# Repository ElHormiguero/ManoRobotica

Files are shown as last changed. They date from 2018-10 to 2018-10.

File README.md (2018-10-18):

# ManoRobotica

Se trata de un brazo robótico impreso en 3d y a escala real, su diseño es de un proyecto de código libre de [grossrc](https://www.thingiverse.com/thing:2269115) al que se le ha añadido dos articulaciones adicionales que añaden grados de libertad. 5 servomotores mueven los dedos gracias a un hilo que simula el tendón humano, el movimiento del dedo gordo se reproduce con dos servos, mientras que el dedo anular y meñique comparten uno solo. Además, un sistema de articulación le permite rotar en los 3 ejes posibles.
El control se realiza mediante un guante que incorpora sensores de flexión en cada dedo y un acelerómetro para obtener la rotación de la mano, los datos se envían por radiofrecuencia a una velocidad de 20 muestras por segundo.



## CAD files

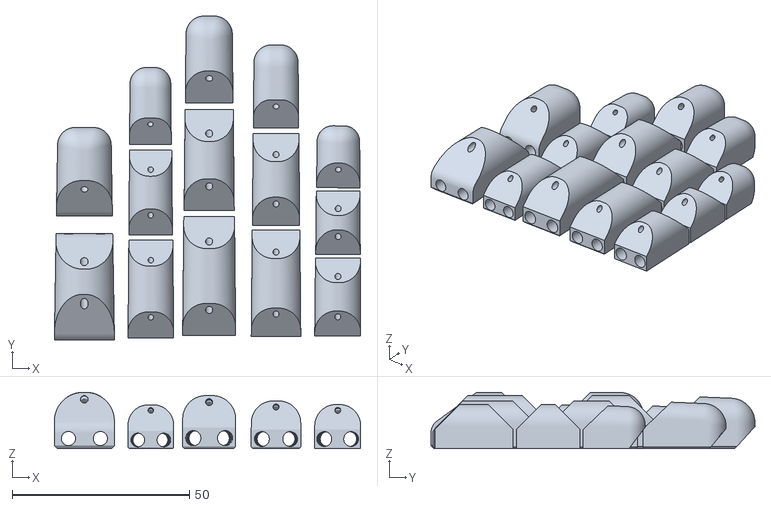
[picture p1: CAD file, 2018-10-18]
Piezas 3D/1Fingerdesign_ALL.stl
86.5 x 91.5 x 15.8

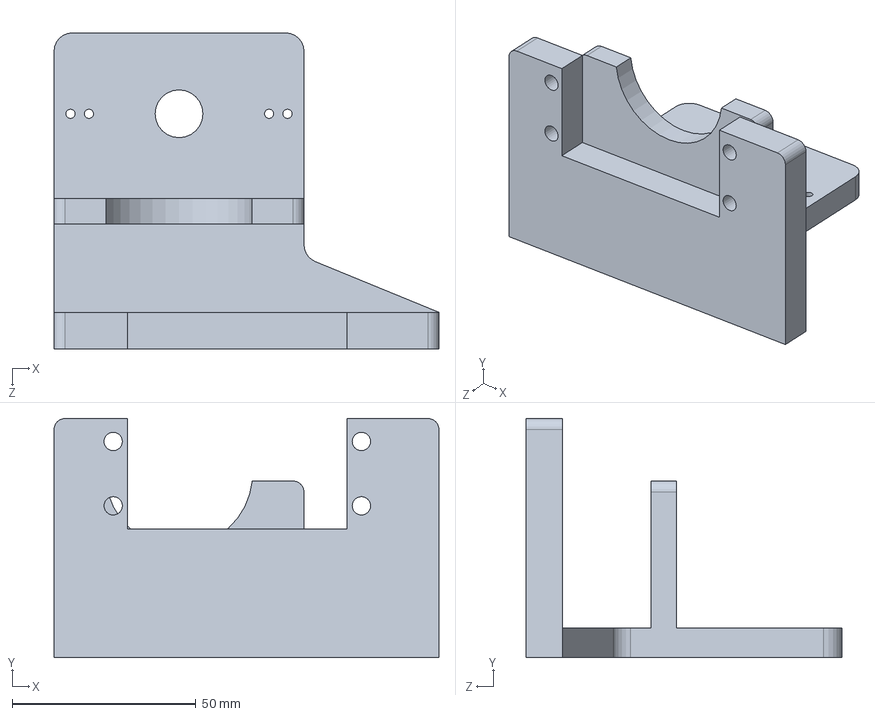
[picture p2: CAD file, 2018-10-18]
Piezas 3D/Piezas añadidas/Articulacion.SLDPRT
104.7 x 65.0 x 86.0 mm

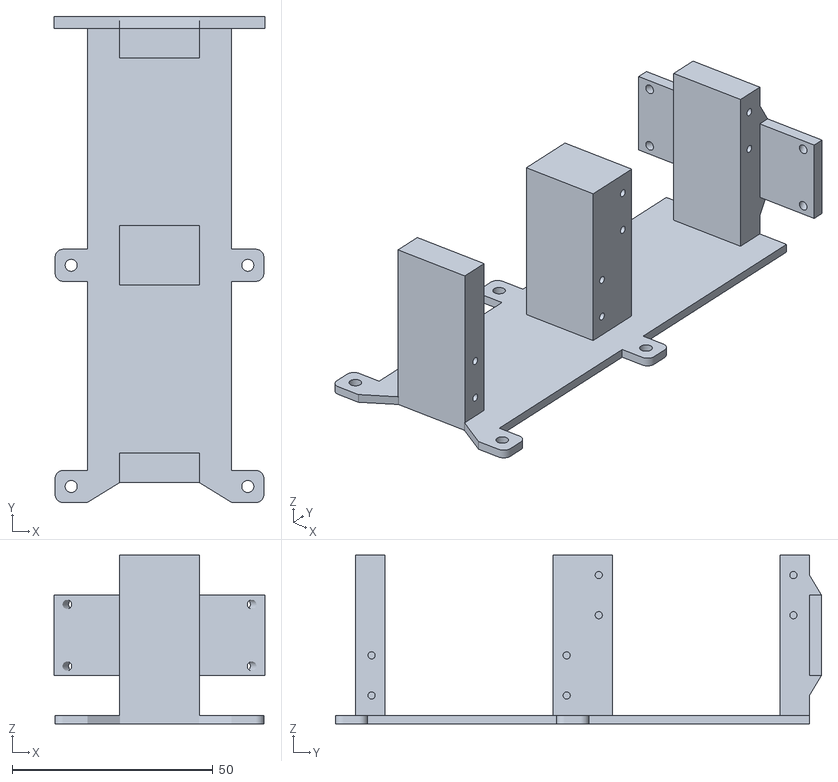
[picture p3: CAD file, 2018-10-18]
Piezas 3D/3Servo_Hold.stl
52.6 x 121.1 x 42.1

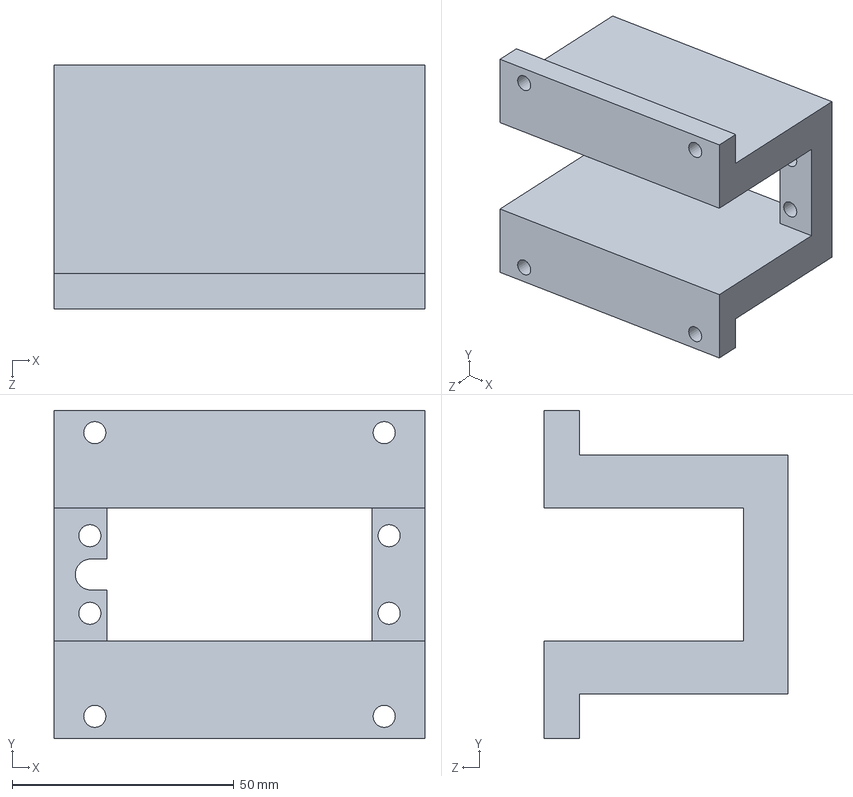
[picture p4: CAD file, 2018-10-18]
Piezas 3D/Piezas añadidas/Base.SLDPRT
83.7 x 74.0 x 55.0 mm

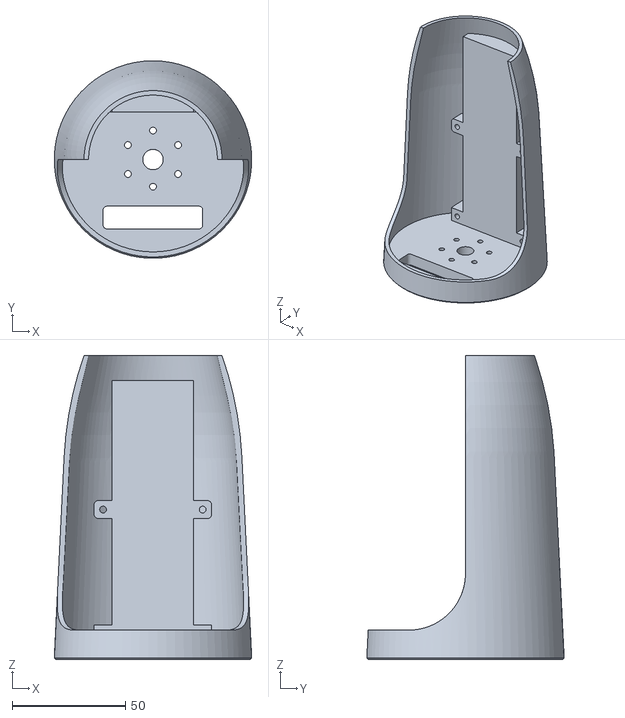
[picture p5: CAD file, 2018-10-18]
Piezas 3D/2Forarm_9-2.stl
87.3 x 87.3 x 134.4

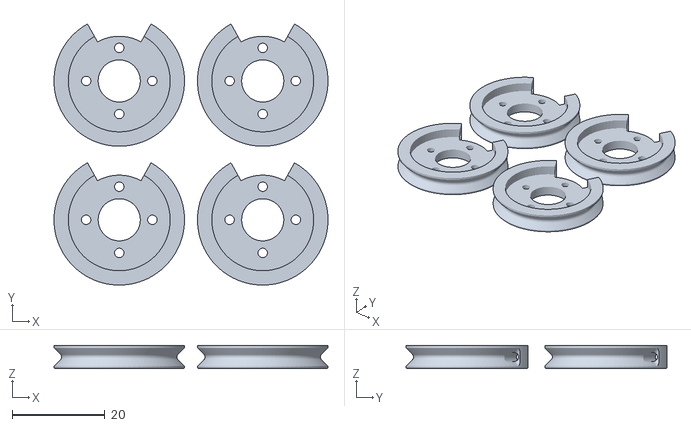
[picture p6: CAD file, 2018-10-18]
Piezas 3D/4ServoHorn.stl
59.2 x 56.4 x 5.00

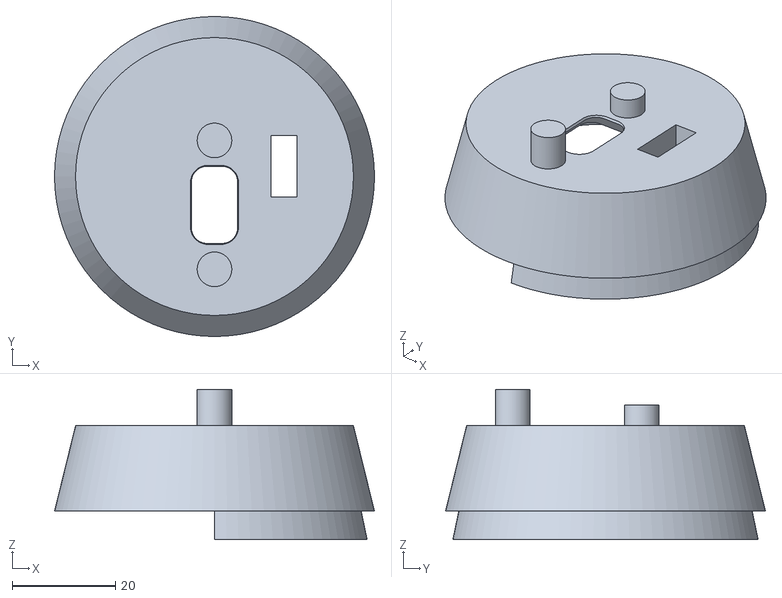
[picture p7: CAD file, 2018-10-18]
Piezas 3D/2Forarm_9-3.stl
62.1 x 62.1 x 29.1

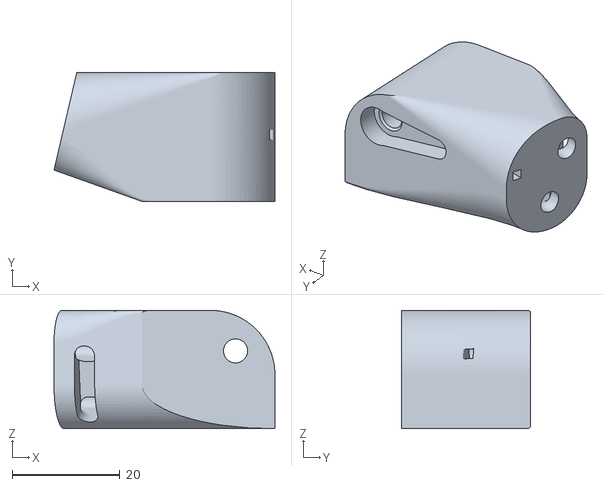
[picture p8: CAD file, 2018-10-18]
Piezas 3D/4Hand5Thumb3.stl
41.1 x 24.0 x 22.0

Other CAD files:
Piezas 3D/Piezas añadidas/Articulacion.STL
Piezas 3D/Piezas añadidas/Base.STL

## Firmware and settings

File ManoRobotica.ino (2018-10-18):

/*
  Brazo robótico con tensores movidos por servomotores según la flexión de los sensores y control de la orientación por un acelerómetro
  Autor: Javier Vargas. El Hormiguero.
  Diseño 3D de grossrc bajo licencia Creative Commons - Attribution - Non-Commercial (https://www.thingiverse.com/thing:2269115)
  https://creativecommons.org/licenses/by-nc/3.0/
*/

/*Conexion de servos
  0 - Articulacion dedo gordo PCA9685 --> 0 (EMAX ES08A) --> V: Step Down D24V50F5
  1 - Dedo gordo PCA9685              --> 1 (MG996R) --> V: Step Down D24V50F5
  2 - Dedo índice PCA9685             --> 2 (MG996R) --> V: Step Down D24V50F5
  3 - Dedo medio PCA9685              --> 3 (MG996R) --> V: Step Down D24V50F5
  4 - Dedo anular + meñique PCA9685   --> 4 (MG996R) --> V: Step Down D24V50F5
  5 - Angulo roll PCA9685             --> 5 (MG996R) --> V: Step Down D24V50F5
  6 - Angulo pitch PWM Arduino        --> 5 (POWER HD 1235MG) --> V: Vbat 7.4V - 2 diodos
  7 - Angulo yaw PWM Arduino          --> 7 (POWER HD 1235MG) --> V: Vbat 7.4V - 2 diodos
*/

//PINES
#define CE_PIN 3
#define CSN_PIN 10
#define PinServoPWM_6 5 //Servo pwm Pitch
#define PinServoPWM_7 7 //Servo pwm Yaw
//Servos conectados de la salida 0 a la 8 del driver
//CONFIGURACION
#define Nservos 9
#define Ndatos 8
#define TimeCero 1000 //(ms) Tiempo sin recibir datos para volver a la posicion inicial

//Servo MG996R (Driver)
#define SERVOMIN  125 // Anchura minima de señal PWM 
#define SERVOMAX  580 // Anchura maxima de señal PWM 
#define ANGULOMAX 220 //Angulo máximo 

//Servo EMAX ES08A (Driver)
#define mSERVOMIN  220 // Anchura minima de señal PWM 
#define mSERVOMAX  580 // Anchura maxima de señal PWM 
#define mANGULOMAX 165 //Angulo máximo

//Servo POWER HD 1235MG (PWM)
#define gSERVOMIN  544 // Anchura minima de señal PWM 
#define gSERVOMAX  2390 // Anchura maxima de señal PWM   
//Angulo de 180º

//Sensor de los dedos (0-gordo, 1-índice, 3-medio, 4-anular, 5-meñique)
const int SensFlex[] = {610, 560, 540, 550, 570};
const int SensNoFlex[] = {780, 780, 780, 745, 785};
//Angulo de los dedos (0-art.gordo, 1-gordo, 2-índice, 3-medio, 4-anular+meñique)
const int AngFlex[] = {50, 170, 115, 60, 50};
const int AngNoFlex[] = {110, 60, 220, 180, 170};
//Angulo de los ejes (0-yaw, 1-pitch, 2-roll)
const int AngMax[] = {180, 120, 180};
const int AngMin[] = {0, 70, 0};
const int AngCero[] = {75, 90, 90};
//Offset
const int Offset[] = {0, 0, 0};

//DRIVER SERVOS PCA
#include <Wire.h>
#include <Adafruit_PWMServoDriver.h>
Adafruit_PWMServoDriver pwm = Adafruit_PWMServoDriver(); //Direccion 0x40
//SERVO POR PWM (ALIMENTADO POR BATERIA)
#include <Servo.h>
Servo servo6, servo7;

//NRF24L01
byte direccion[5] = {'h', 'o', 'r', 'm', 'i'}; //Variable con la dirección del canal por donde se va a transmitir
#include <SPI.h>
#include <nRF24L01.h>
#include <RF24.h>
RF24 radio(CE_PIN, CSN_PIN);
float Datos[Ndatos] = {0, 0, 0, 0, 0, 0, 0, 0};

unsigned long m = 0;
boolean e = 0;

void setup() {
  Serial.begin(115200);

  //Inicio driver servos
  pwm.begin();
  pwm.setPWMFreq(60);  //Frecuencia de 60Hz en servos analógicos

  //Inicio del NRF24L01
  radio.begin();
  radio.openReadingPipe(1, direccion);
  radio.startListening();   //empezamos a escuchar por el canal
  delay(500);


  //Inicio servos pwm
  servo6.attach(PinServoPWM_6, gSERVOMIN, gSERVOMAX);
  servo7.attach(PinServoPWM_7, gSERVOMIN, gSERVOMAX);

}

//////////////////////////////////
///////////////LOOP///////////////
//////////////////////////////////

void loop() {

  //DATOS RECIBIDOS POR RF
  if (radio.available()) {
    m = millis();
    //Datos recibidos por RF
    radio.read(Datos, sizeof(Datos));
    //Rotamos el brazo segun Yaw, Pitch y Roll
    RotarBrazo(Datos[0], Datos[1], Datos[2]);
    //Movemos los dedos sengun los sensores de flexion
    MoverDedos(Datos[3], Datos[4], Datos[5], Datos[6], Datos[7]);
  }

  //Vuelta a la posicion inicial si no recibe datos en TimeCero ms
  if (millis() > m + TimeCero) ServoCero();


}

//////////////////////////////////
//////////////////////////////////
//////////////////////////////////

void RotarBrazo(float yaw, float pitch, float roll) {
  //Yaw
  int AngYaw = constrain(AngCero[0] - yaw - Offset[0], AngMin[0], AngMax[0]);
  MoverServo(7, AngYaw);
  //Pitch
  int AngPitch = constrain(AngCero[1] - pitch - Offset[1], AngMin[1], AngMax[1]);
  MoverServo(6, AngPitch);
  //Roll
  int AngRoll = constrain(AngCero[2] + roll + Offset[2], AngMin[2], AngMax[2]);
  MoverServo(5, AngRoll);
}

void MoverDedos(int d1, int d2, int d3, int d4, int d5) {
  //Articulacion dedo gordo + dedo
  d1 = constrain(d1, SensFlex[0], SensNoFlex[0]);
  MoverServo(0, map(d1, SensFlex[0], SensNoFlex[0], AngFlex[0], AngNoFlex[0]));
  MoverServo(1, map(d1, SensFlex[0], SensNoFlex[0], AngFlex[1], AngNoFlex[1]));
  //Dedo índice
  d2 = constrain(d2, SensFlex[1], SensNoFlex[1]);
  MoverServo(2, map(d2, SensFlex[1], SensNoFlex[1], AngFlex[2], AngNoFlex[2]));
  //Dedo medio
  d3 = constrain(d3, SensFlex[2], SensNoFlex[2]);
  MoverServo(3, map(d3, SensFlex[2], SensNoFlex[2], AngFlex[3], AngNoFlex[3]));
  //Dedo anular + meñique
  d4 = constrain(d4, SensFlex[3], SensNoFlex[3]);
  d5 = constrain(d5, SensFlex[4], SensNoFlex[4]);
  int dMed = (d4 + d5) / 2;
  int SensFlexMed = (SensFlex[3] + SensFlex[4]) / 2;
  int SensNoFlexMed = (SensNoFlex[3] + SensNoFlex[4]) / 2;
  MoverServo(4, map(dMed, SensFlexMed, SensNoFlexMed, AngFlex[4], AngNoFlex[4]));
}

void MoverServo(int S, int A) {
  //EMAX ES08A
  if (S == 0) {
    pwm.setPWM(S, 0, map(A, 0, mANGULOMAX, mSERVOMIN, mSERVOMAX));
  }
  //MG996R
  else if (S <= 5) {
    pwm.setPWM(S, 0, map(A, 0, ANGULOMAX, SERVOMIN, SERVOMAX));
  }
  //POWER HD 1235MG
  else if (S <= 7) {
    if (S == 6) servo6.write(A);
    if (S == 7) servo7.write(A);
  }
}

void ServoCero() {
  MoverServo(0, AngNoFlex[0]);
  MoverServo(1, AngNoFlex[1]);
  MoverServo(2, AngNoFlex[2]);
  MoverServo(3, AngNoFlex[3]);
  MoverServo(4, AngNoFlex[4]);
  MoverServo(5, AngCero[2]);
  MoverServo(6, AngCero[1]);
  MoverServo(7, AngCero[0]);
}

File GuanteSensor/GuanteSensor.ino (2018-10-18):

/*
  Control de un acelerómeto por DMP y sensado de flexión con envío por radiofrecuencia. Programado sobre Teensy 3.6
  Autor: Javier Vargas. El Hormiguero.
  Diseño 3D de grossrc bajo licencia Creative Commons - Attribution - Non-Commercial (https://www.thingiverse.com/thing:2269115)
  https://creativecommons.org/licenses/by-nc/3.0/
*/

//CONFIGURACION
#define Muestreo 50 //Frecuencia de muestreo de lectura y envio de datos
#define Nsensores 5 //Sensores de flexion
#define Kf 0.6f //Filtro de lectura de los sensores de flexion
#define Ka 0.8f  //Filtro de lectura del acelerometro
#define AngMax 75 //Angulo de desviación máximo respecto al 0 en cualquiera de los ejes

//PINES
#define PinCE 27
#define PinCSN 28
#define PinInt 2
#define PinR 29
#define PinG 31
#define PinB 32
const int PinFlex[] = {17, 20, 21, 22, 23}; //Sensores SPRK-SEN-10264
//MOSI 11, MISO 12, SCK 13, SDA 18, SCL 19

//Libreria Parpadeo led
#include "BlinkLed.h"
BlinkLed LedR(PinR, 250);
BlinkLed LedG(PinG, 100, 900);
BlinkLed LedB(PinB, 500);

//MPU 6050
#include "I2Cdev.h"
#include "MPU6050_6Axis_MotionApps20.h"
#include "Wire.h"
MPU6050 mpu(0x68); //Direccion del dispositivo 0x68
Quaternion q; // [w, x, y, z] quaternion container
VectorFloat gravity; // [x, y, z] gravity vector
boolean DataReady = 0; //Datos de del DMP listos, aviso por interrupcion)
uint16_t packetSize = 42; //Tamaño del paquete del DMP (por defecto 42 bytes)
float Yoffset = 0, Poffset = 0, Roffset = 0; //Offset de las medidas

//NRF24L01
byte direccion[5] = {'h', 'o', 'r', 'm', 'i'}; //Variable con la dirección del canal por donde se va a transmitir

#include <SPI.h>
#include <nRF24L01.h>
#include <RF24.h>
RF24 radio(PinCE, PinCSN);
//float Datos[Nsensores + 3];

float Datos[] = {0, 0, 0, 0, 0, 0, 0, 0};

unsigned long m = 0;
float Flexion[] = {0, 0, 0, 0, 0}; //Nivel de flexión de los sensores de los dedos
float ypr[3] = {0, 0, 0}; //Variables Yaw, Pitch y Roll
boolean AnguloOK = 0;

void setup() {
  Serial.begin(115200);

  //Inicio Led
  LedR.begin();
  LedG.begin();
  LedB.begin();
  LedB.NoBlink();
  LedB.On();

  delay(1000);

  //PinMode
  for (int i = 0; i < Nsensores; i++) {
    pinMode(PinFlex[i], INPUT);
  }

  //inicializamos el NRF24L01
  radio.begin();
  radio.openWritingPipe(direccion);

  //Inicio del MPU DMP (Digital Motion Processor)
#if I2CDEV_IMPLEMENTATION == I2CDEV_ARDUINO_WIRE
  Wire.begin();
  TWBR = 24; // 400kHz I2C clock (200kHz if CPU is 8MHz)
#elif I2CDEV_IMPLEMENTATION == I2CDEV_BUILTIN_FASTWIRE
  Fastwire::setup(400, true);
#endif
  mpu.dmpInitialize();
  mpu.setXAccelOffset(-595);
  mpu.setYAccelOffset(-2773);
  mpu.setZAccelOffset(-77);
  mpu.setXGyroOffset(-29);
  mpu.setYGyroOffset(-4);
  mpu.setZGyroOffset(-3);
  mpu.setDMPEnabled(true);
  packetSize = mpu.dmpGetFIFOPacketSize(); //Tamaño del paquete de datos almacenado en la memoria FIFO
  attachInterrupt(digitalPinToInterrupt(PinInt), Interrupcion, RISING);


  LedB.Off();
}

//////////////////////////////////
///////////////LOOP///////////////
//////////////////////////////////

void loop() {


  //Loop principal
  if (millis() / Muestreo != m) {
    m = millis() / Muestreo;
    //Lectura de los sensores de flexion
    LecturaDedos();
    //Envio RF
    EnvioRF();
    //Lectura del acelerometro correcta
    if (AnguloOK) {
      LedR.Off(), LedG.On();
    }
    //Lectura incorrecta, no enviamos datos
    else {
      LedR.On(), LedG.Off();
    }
  }

  //Lectura de IMU por interrupcion del DMP
  LecturaIMU();

  //Estado del led
  LedR.Update();
  LedG.Update();
  LedB.Update();

}

//////////////////////////////////
//////////////////////////////////
//////////////////////////////////

void EnvioRF() {

  //Datos a enviar
  Datos[0] = ypr[0];
  Datos[1] = ypr[2]; //Pitch y roll cambiados**
  Datos[2] = ypr[1];
  Datos[3] = Flexion[0];
  Datos[4] = Flexion[1];
  Datos[5] = Flexion[2];
  Datos[6] = Flexion[3];
  Datos[7] = Flexion[4];

  //Envio por RF
  radio.write(Datos, sizeof(Datos));
}

void LecturaDedos() {
  for (int i = 0; i < Nsensores; i++) {
    //Lectura analogica y filtrado de datos
    Flexion[i] = Kf * analogRead(PinFlex[i]) + (1 - Kf) * Flexion[i];
//    Serial.print(Flexion[i]);
//    Serial.print(" / ");
  }
//  Serial.println();
}

void LecturaIMU() {
  static uint16_t fifoCount = 0; //Bytes en memoria FIFO
  static uint8_t mpuIntStatus; //Estado de la interrupcion
  static uint8_t fifoBuffer[64]; //Memoria FIFO
  static float yprAnt[3]; //Lecturas anteriores

  //DATOS PREPARADOS
  if (DataReady) {
    DataReady = 0;

    mpuIntStatus = mpu.getIntStatus(); //Estado de la interrupcion
    fifoCount = mpu.getFIFOCount(); //Estado de la memoria FIFO

    //ERROR DE DATOS
    if ((mpuIntStatus & 0x10) || fifoCount == 1024) mpu.resetFIFO(); //Overflow de datos, no realizamos la lectura

    //DATOS CORRECTOS
    else if (mpuIntStatus & 0x02) { //Datos correctos

      //Lectura
      while (fifoCount < packetSize) fifoCount = mpu.getFIFOCount();
      mpu.getFIFOBytes(fifoBuffer, packetSize);
      fifoCount -= packetSize;
      mpu.dmpGetQuaternion(&q, fifoBuffer);
      mpu.dmpGetGravity(&gravity, &q);
      mpu.dmpGetYawPitchRoll(ypr, &q, &gravity);

      //Offset
      ypr[0] = ypr[0] * 180 / M_PI + Yoffset;
      ypr[1] = ypr[1] * 180 / M_PI + Poffset;
      ypr[2] = ypr[2] * 180 / M_PI + Roffset;

      //Filtrado
      for (int i = 0; i < 3; i++) ypr[i] = Ka * ypr[i] + (1 - Ka) * yprAnt[i];

      //Evitar gimbal lock
      if (abs(ypr[1]) > AngMax || abs(ypr[2]) > AngMax) {
        AnguloOK = 0;
        //Mantenemos lecturas anteriores
        for (int i = 0; i < 3; i++) ypr[i] = yprAnt[i];
      }
      else AnguloOK = 1;

      //Actualizacion de lectura anterior
      for (int i = 0; i < 3; i++) yprAnt[i] = ypr[i];

      //      Serial.print("ypr\t");
      //      Serial.print(ypr[0]);
      //      Serial.print("\t");
      //      Serial.print(ypr[1]);
      //      Serial.print("\t");
      //      Serial.println(ypr[2]);
    }
  }
}

void Interrupcion() {
  DataReady = 1;
}
